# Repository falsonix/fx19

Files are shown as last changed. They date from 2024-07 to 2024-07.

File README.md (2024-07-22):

# fx19
Custom mechanical number pad for personal computers

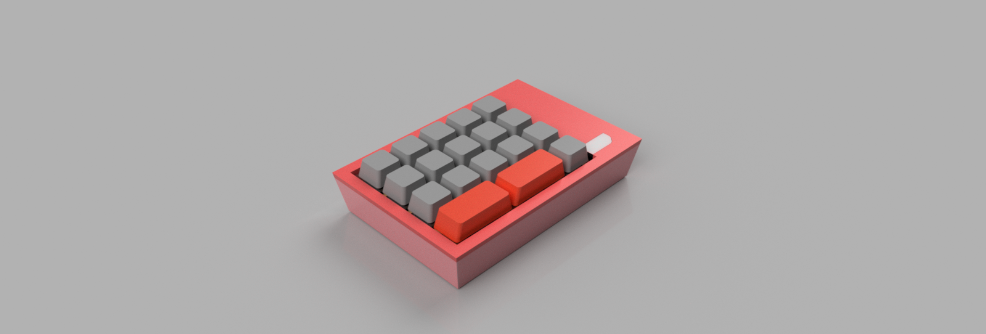
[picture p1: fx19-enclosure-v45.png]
3d render of the fx19


# License information
This work is licensed under a
[Creative Commons Attribution-ShareAlike 4.0 International License][cc-sa].

[][cc-sa]

[cc-sa]: http://creativecommons.org/licenses/by-sa/4.0/
[cc-sa-image]: https://i.creativecommons.org/l/by-sa/4.0/88x31.png
[cc-sa-shield]: https://mirrors.creativecommons.org/presskit/buttons/88x31/svg/by-sa.svg

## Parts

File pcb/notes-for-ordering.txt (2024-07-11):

I had my boards made by JLCPCB, but other services such as PCBWAY and Aisler can make circuit boards for you too.

All files needed for having PCBs professionally made are in the 'production' folder, and files for you to modify yourself are in the 'source' folder.

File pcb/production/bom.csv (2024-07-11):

Designator | Footprint | Quantity | Value | LCSC Part #
C1, C2 | 0805 | 2 | 22p
C10, C11, C12, C13, C14, C9 | 0805 | 6 | 100nf
C3, C4, C5, C6 | 0805 | 4 | 0.1u
C7 | 0805 | 1 | 4.7u
C8 | 0805 | 1 | 1u
D1, D10, D11, D12, D13, D14, D15, D16, D17, D18, D2, D3, D4, D5, D6, D7, D8, D9 | D_SOD123_axial | 18 | D
J1 | USB_C_Receptacle_HRO_TYPE-C-31-M-12 | 1 | USB_C_Receptacle_USB2.0_14P
K1, K10, K11, K12, K13, K14, K15, K16, K17, K18, K2, K3, K4, K5, K6, K7, K8, K9 | Mx_Alps_100 | 18 | KEYSW
LED1, LED2, LED3, LED4, LED5, LED6 | LED-SMD_4P-L1.3-W1.3-P0.80_WS2812E-1313 | 6 | WS2812E-1313
PWRLED1 | 1206 | 1 | LED
R1, R2 | 0805 | 2 | 10k
R3, R4 | 0805 | 2 | 5.1k
R5, R6 | 0805 | 2 | 22
SW1 | SW_SPST_TL3342 | 1 | SW_PUSH
U1 | TQFP-44_10x10mm_P0.8mm | 1 | ATMEGA32U4
XTAL1 | Crystal_SMD_SeikoEpson_FA238-4Pin_3.2x2.5mm_HandSoldering | 1 | FA-238 16.0000MB-C3

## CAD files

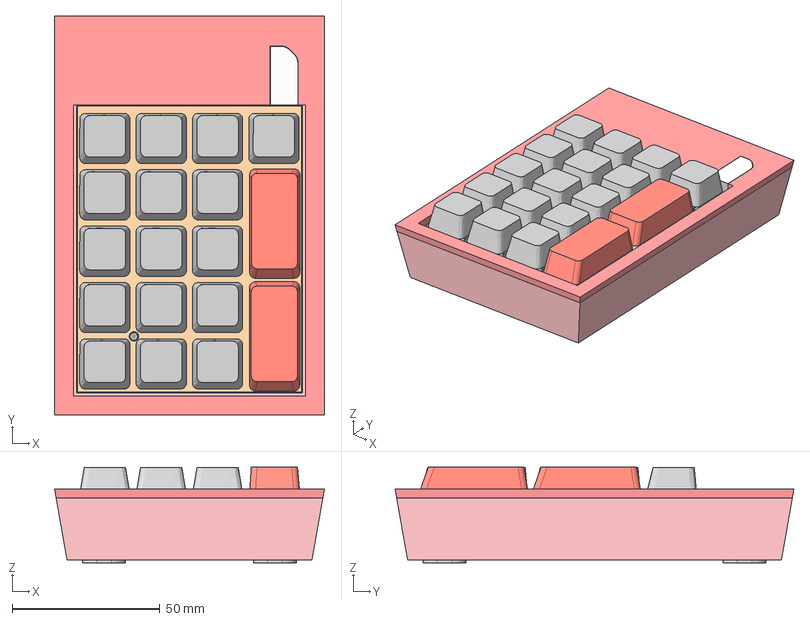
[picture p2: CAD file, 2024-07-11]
case/fx19-cad.step
91.3 x 134.8 x 32.4 mm
Button x 18
Pins x 18
R_0805_2012Metric x 6
C_0805_2012Metric x 14
Crystal_SMD_SeikoEpson_FA238-4Pin_3.2x2.5mm_HandSoldering
TQFP_44_10x10mm_P08mm
SW_SPST_TL3342
numpad_project_PCB
ConPins
PcbPins
Mold
Frame
Broached Hexagon Socket Head Cap Screw ANSI B18.3.1M - M3x0.5 x 6 Ste el Grade 2 Plain v1 x 4
keycap x 16

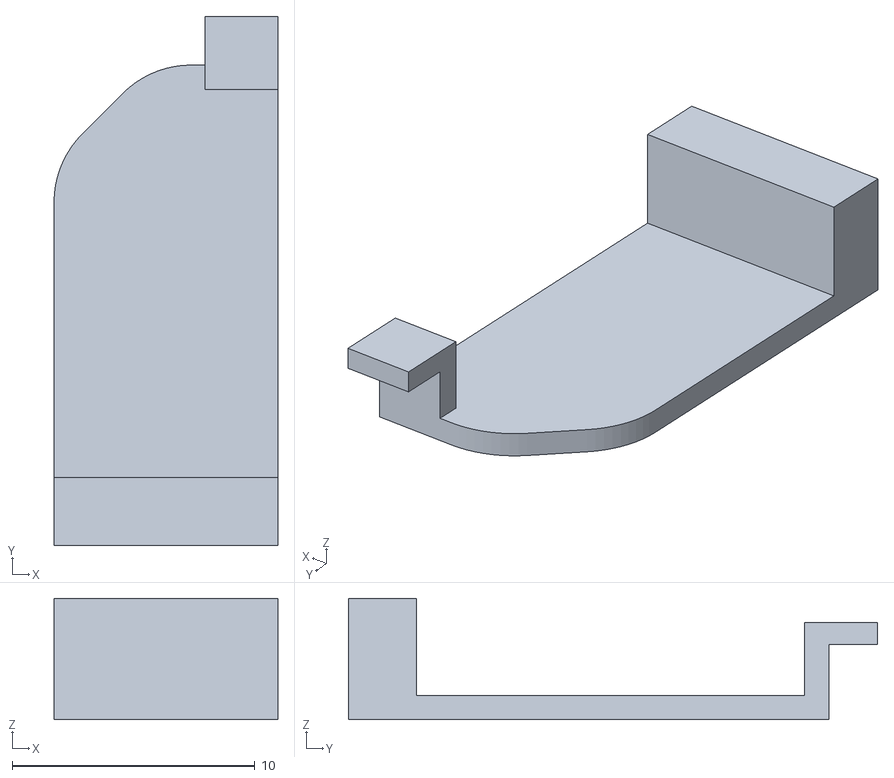
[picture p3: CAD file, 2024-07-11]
case/diffuser.stl
9.23 x 21.8 x 5.00

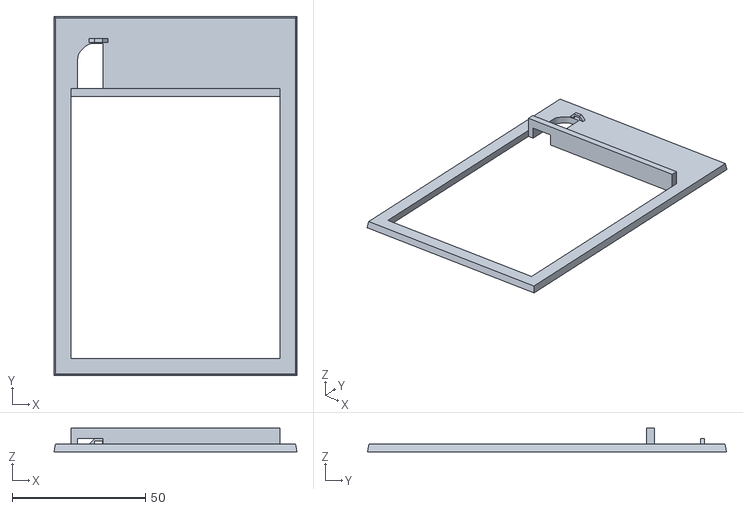
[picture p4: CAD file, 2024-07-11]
case/topcase.stl
91.3 x 134.8 x 9.00

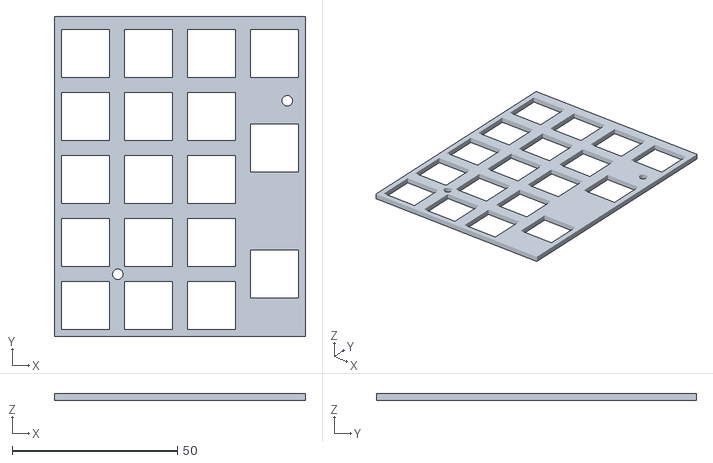
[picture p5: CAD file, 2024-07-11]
case/midsection.stl
75.9 x 96.7 x 2.00

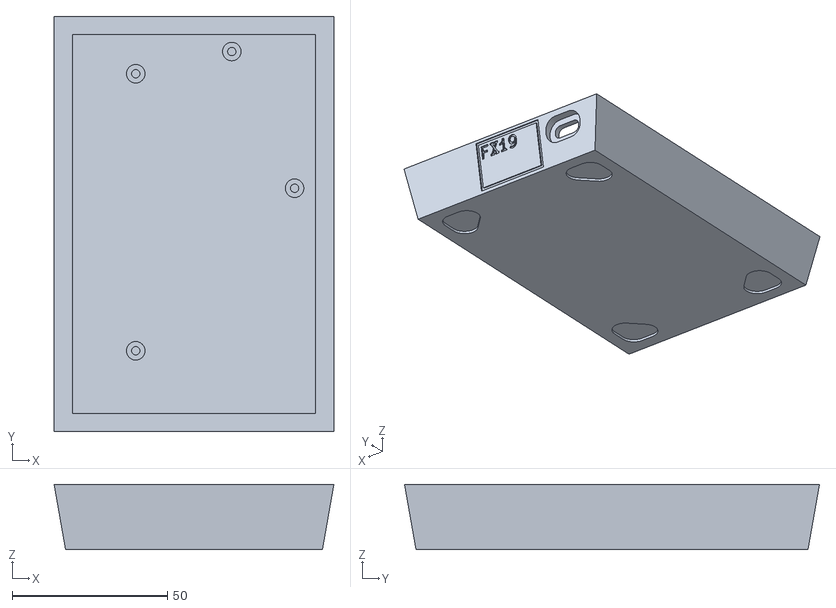
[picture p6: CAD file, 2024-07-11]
case/bottomcase.stl
90.2 x 133.8 x 21.0

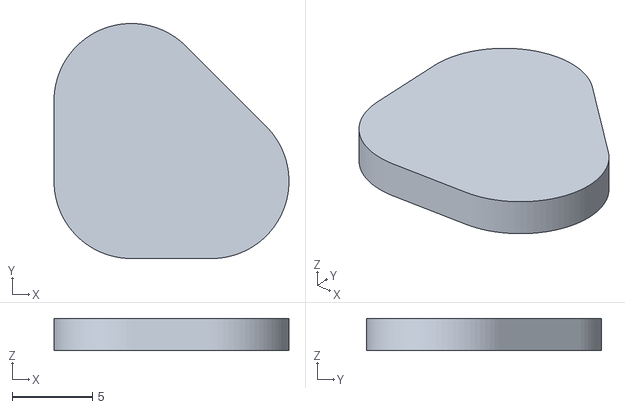
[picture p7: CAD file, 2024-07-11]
case/rubberfoot.stl
14.6 x 14.6 x 2.00

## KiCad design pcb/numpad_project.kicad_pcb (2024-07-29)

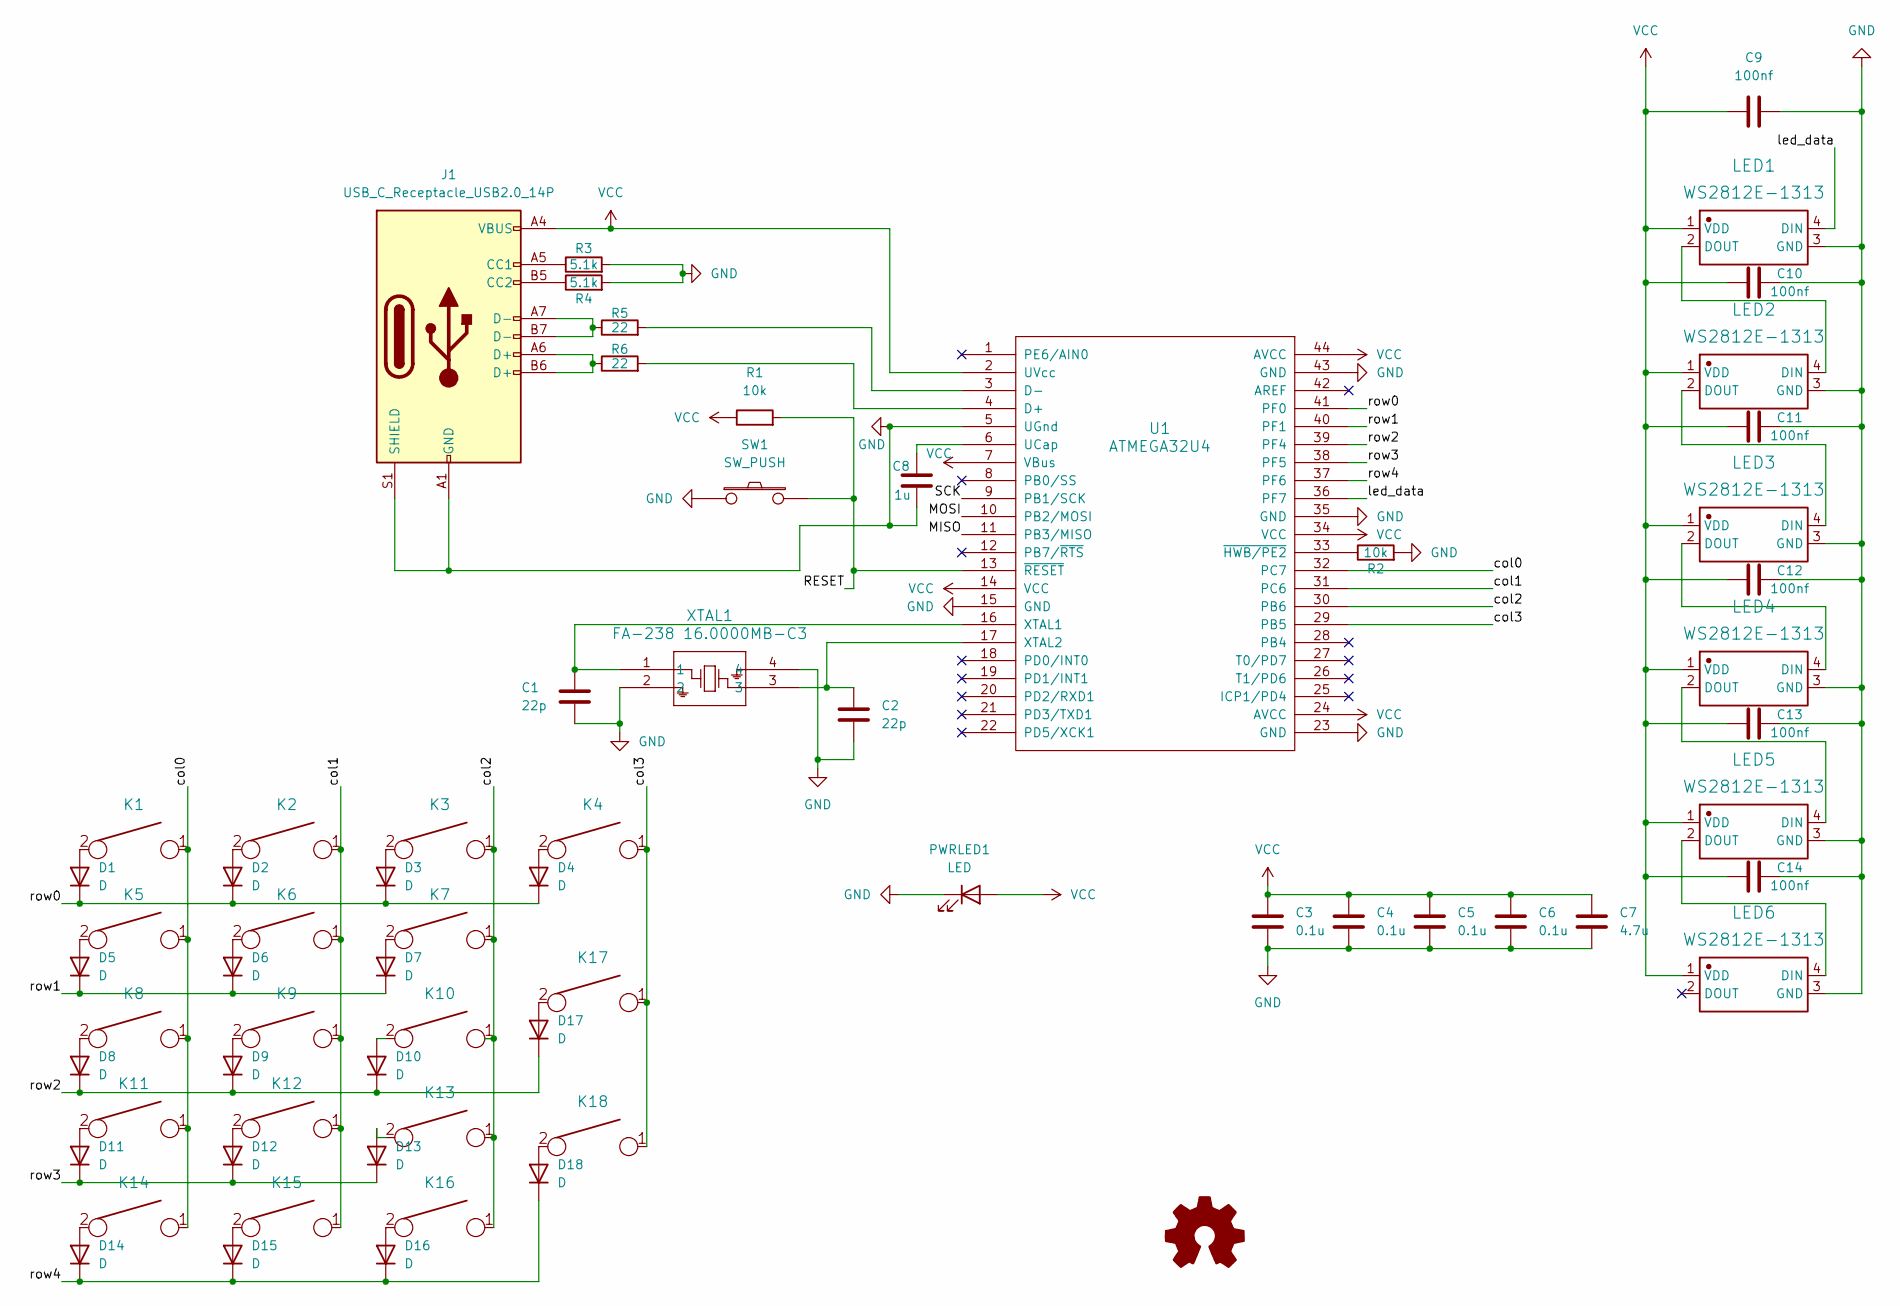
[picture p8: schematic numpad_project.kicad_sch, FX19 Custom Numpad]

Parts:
C1, C2: 22p; C_0805_2012Metric_Pad1.18x1.45mm_HandSolder
C3, C4, C5, C6: 0.1u; C_0805_2012Metric_Pad1.18x1.45mm_HandSolder
C7: 4.7u; C_0805_2012Metric_Pad1.18x1.45mm_HandSolder
C8: 1u; C_0805_2012Metric_Pad1.18x1.45mm_HandSolder
C9, C10, C11, C12, C13, C14: 100nf; C_0805_2012Metric_Pad1.18x1.45mm_HandSolder
D1, D2, D3, D4, D5, D6, D7, D8, D9, D10, D11, D12, D13, D14, D15, D16, D17, D18: D; D_SOD123_axial
J1: USB_C_Receptacle_USB2.0_14P; USB_C_Receptacle_HRO_TYPE-C-31-M-12
K1, K2, K3, K4, K5, K6, K7, K8, K9, K10, K11, K12, K13, K14, K15, K16, K17, K18: KEYSW; Mx_Alps_100
LED1, LED2, LED3, LED4, LED5, LED6: WS2812E-1313; LED-SMD_4P-L1.3-W1.3-P0.80_WS2812E-1313; Manufacturer Part WS2812E-1313
PWRLED1: LED; LED_1206_3216Metric_Pad1.42x1.75mm_HandSolder
R1, R2: 10k; R_0805_2012Metric_Pad1.20x1.40mm_HandSolder
R3, R4: 5.1k; R_0805_2012Metric_Pad1.20x1.40mm_HandSolder
R5, R6: 22; R_0805_2012Metric_Pad1.20x1.40mm_HandSolder
SW1: SW_PUSH; SW_SPST_TL3342
U1: ATMEGA32U4; TQFP-44_10x10mm_P0.8mm
XTAL1: FA-238 16.0000MB-C3; Crystal_SMD_SeikoEpson_FA238-4Pin_3.2x2.5mm_HandSoldering

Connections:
/MISO: U1.11 (PB3/MISO); also elsewhere on the board
/MOSI: U1.10 (PB2/MOSI); also elsewhere on the board
/RESET: R1.2, SW1.2, U1.13 (~RESET); also elsewhere on the board
/SCK: U1.9 (PB1/SCK); also elsewhere on the board
/col0: K1.1, K5.1, K8.1, K11.1, K14.1, U1.32 (PC7)
/col1: K2.1, K6.1, K9.1, K12.1, K15.1, U1.31 (PC6)
/col2: K3.1, K7.1, K10.1, K13.1, K16.1, U1.30 (PB6)
/col3: K4.1, K17.1, K18.1, U1.29 (PB5)
/led_data: LED1.4 (DIN), U1.36 (PF7)
/row0: D1.1 (K), D2.1 (K), D3.1 (K), D4.1 (K), U1.41 (PF0)
/row1: D5.1 (K), D6.1 (K), D7.1 (K), U1.40 (PF1)
/row2: D8.1 (K), D9.1 (K), D10.1 (K), D17.1 (K), U1.39 (PF4)
/row3: D11.1 (K), D12.1 (K), D13.1 (K), U1.38 (PF5)
/row4: D14.1 (K), D15.1 (K), D16.1 (K), D18.1 (K), U1.37 (PF6)
GND: C1.2, C2.2, C3.2, C4.2, C5.2, C6.2, C7.2, C8.2, C9.2, C10.2, C11.2, C12.2, C13.2, C14.2, J1.A1 (GND), J1.A12 (GND), J1.B1 (GND), J1.B12 (GND), J1.S1 (SHIELD), LED1.3 (GND), LED2.3 (GND), LED3.3 (GND), LED4.3 (GND), LED5.3 (GND), LED6.3 (GND), PWRLED1.1 (K), R2.2, R3.2, R4.2, SW1.1, U1.5 (UGnd), U1.15 (GND), U1.23 (GND), U1.35 (GND), U1.43 (GND), XTAL1.2, XTAL1.4
unnamed: D1.2 (A), K1.2
unnamed: D2.2 (A), K2.2
unnamed: D3.2 (A), K3.2
unnamed: D4.2 (A), K4.2
unnamed: D5.2 (A), K5.2
unnamed: D6.2 (A), K6.2
unnamed: D7.2 (A), K7.2
unnamed: D8.2 (A), K8.2
unnamed: D9.2 (A), K9.2
unnamed: D10.2 (A), K10.2
unnamed: D11.2 (A), K11.2
unnamed: D12.2 (A), K12.2
unnamed: D13.2 (A), K13.2
unnamed: D14.2 (A), K14.2
unnamed: D15.2 (A), K15.2
unnamed: D16.2 (A), K16.2
unnamed: D17.2 (A), K17.2
unnamed: D18.2 (A), K18.2
unnamed: J1.A5 (CC1), R3.1
unnamed: J1.B5 (CC2), R4.1
unnamed: J1.A6 (D+), J1.B6 (D+), R6.1
unnamed: J1.A7 (D-), J1.B7 (D-), R5.1
unnamed: LED1.2 (DOUT), LED2.4 (DIN)
unnamed: LED2.2 (DOUT), LED3.4 (DIN)
unnamed: LED3.2 (DOUT), LED4.4 (DIN)
unnamed: LED4.2 (DOUT), LED5.4 (DIN)
unnamed: LED5.2 (DOUT), LED6.4 (DIN)
unnamed: R6.2, U1.4 (D+)
unnamed: R5.2, U1.3 (D-)
unnamed: C8.1, U1.6 (UCap)
unnamed: C1.1, U1.16 (XTAL1), XTAL1.1
unnamed: C2.1, U1.17 (XTAL2), XTAL1.3
unnamed: R2.1, U1.33 (~HWB/PE2)
VCC: C3.1, C4.1, C5.1, C6.1, C7.1, C9.1, C10.1, C11.1, C12.1, C13.1, C14.1, J1.A4 (VBUS), J1.A9 (VBUS), J1.B4 (VBUS), J1.B9 (VBUS), LED1.1 (VDD), LED2.1 (VDD), LED3.1 (VDD), LED4.1 (VDD), LED5.1 (VDD), LED6.1 (VDD), PWRLED1.2 (A), R1.1, U1.2 (UVcc), U1.7 (VBus), U1.14 (VCC), U1.24 (AVCC), U1.34 (VCC), U1.44 (AVCC); also elsewhere on the board

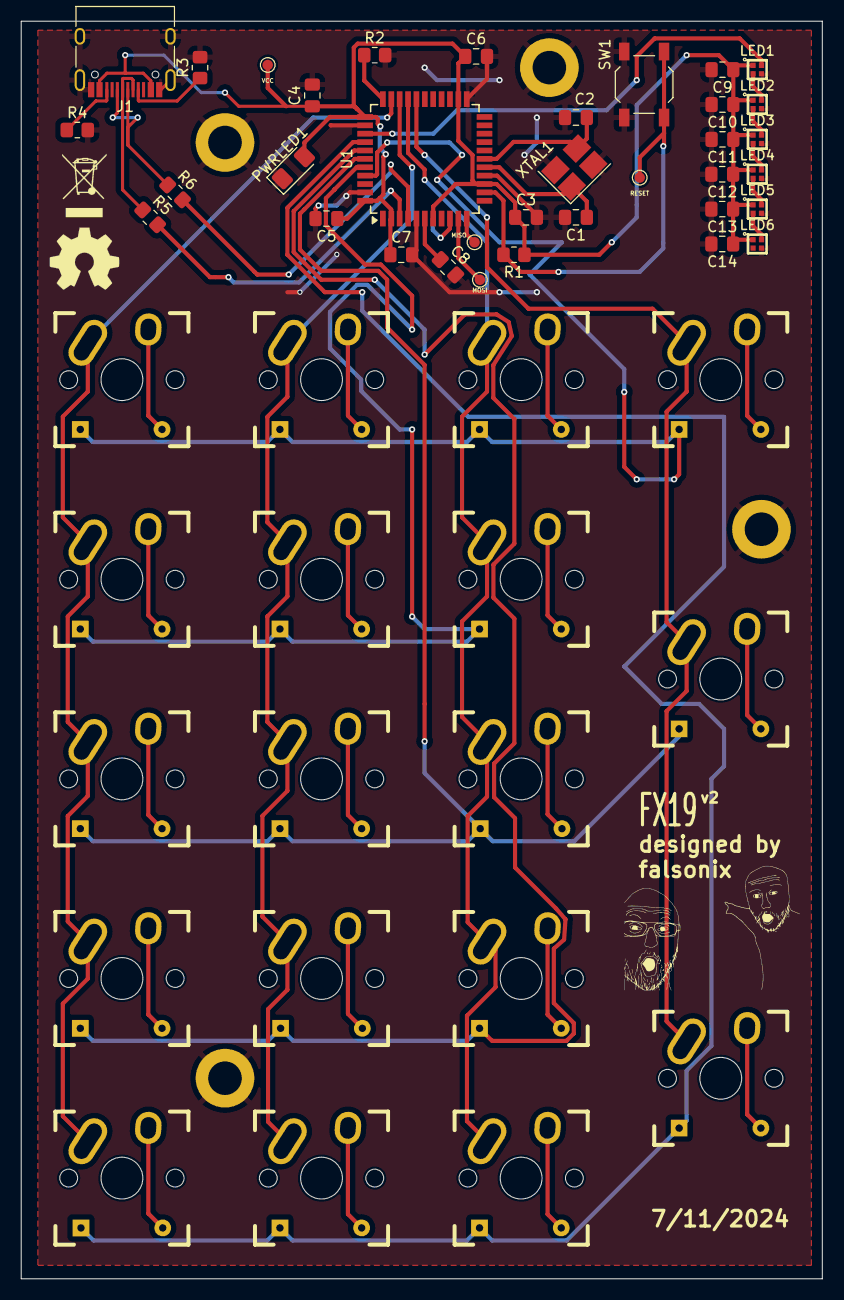
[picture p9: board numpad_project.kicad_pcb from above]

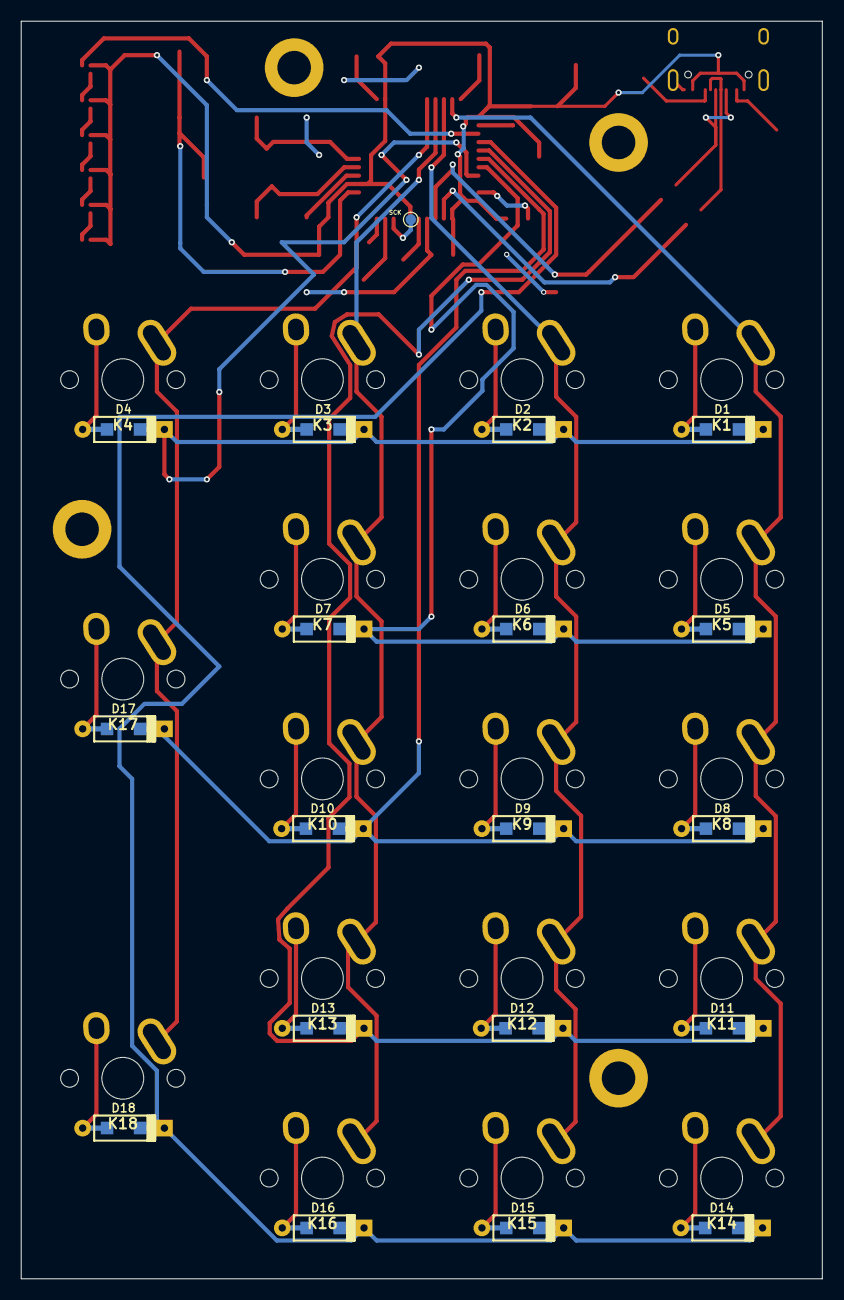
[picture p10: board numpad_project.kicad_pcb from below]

Board: 2 copper layers, 76.5 x 120.0 mm, 72 parts (19 on the bottom side), 49 nets.

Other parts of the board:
MISO: TestPoint_Pad_D1.0mm
MOSI: TestPoint_Pad_D1.0mm
RESET: TestPoint_Pad_D1.0mm
SCK: TestPoint_Pad_D1.0mm
VCC: TestPoint_Pad_D1.0mm

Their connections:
/MISO: MISO.1; also elsewhere on the board
/MOSI: MOSI.1; also elsewhere on the board
/RESET: RESET.1; also elsewhere on the board
/SCK: SCK.1; also elsewhere on the board
VCC: VCC.1; also elsewhere on the board

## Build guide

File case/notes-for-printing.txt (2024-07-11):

All files can be printed with a standard FDM machine in their current orientations. If you encounter the issue of the keycaps not fitting onto your switches due to tolerances, please scale them up by 1%.

####### NOTE #######
The diffuser should be printed with a light colored filament for maximum effect from the lights.

Keycap Models:
- 1U keycap model is not mine, check here: https://www.printables.com/model/188979-flat-keycap-cherry-mx
- 2U keycap model is mine, but is a remix of the 1U found above, and can be found here: https://www.printables.com/model/939066-flat-cherry-mx-keycap-2u-size-remix

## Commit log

2024-07-11 add production files
    [bom.csv, designators.csv, positions.csv]
2024-07-11 add printing files
    [bottomcase.stl, midsection.stl, rubberfoot.stl]
2024-07-11 add more printing files
    [diffuser.stl, topcase.stl]
2024-07-11 Rename fx19-enclosure v45.png to fx19-enclosure-v45.png
2024-07-11 add source files
    [fx19-cad.step]
